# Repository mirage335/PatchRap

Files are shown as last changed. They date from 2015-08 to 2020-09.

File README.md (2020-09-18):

Copyright (C) 2015-2017 mirage335
See the end of the file for license conditions.
See license.txt for PatchRap license conditions.

'PatchPanel' initially designed for RepRap 3D printers to replace PCB terminal blocks with RJ45 jacks. Applicable to a wide variety of systems, including CNC machines, vehicles, factory automation, test equipment, and more.

Primary guidance for the standard should be taken from this README.

ANY CONFLICTING INFORMATION IN ANY OTHER DOCUMENTATION SHOULD BE DEFERRED TO THIS README UNLESS EXPLICITLY STATED OTHERWISE.

# Usage

GenericRap is the reference implementation, includes multiple connectors and headers to adapt RepRap motherboard terminals to internal step-down voltage converters, XT60 power connectors, shielded RJ45/8P8C connectors, and various peripherials (eg. steppers, limit switches, thermistors, hot-ends etc).

Breadboard friendly, the PCB layout includes appropriately spaced headers. In effect, a breadboard can be used as a backplane for power sharing and mechanical support, as well as to arrange even more wiring as needed.

Cat 6A S/FTP cabling recommended.

## Extract

Compacted design files are provided under '_out*' directories for inclusion into other projects. Please respect all relevant copyright licenses and distribute these files only with corresponding source (eg. the complete PatchRap repository).

To include these files in gEDA projects, a few routine modifications should be made.

Directory - create.

```
mkdir -p ./_out_PatchRap_symbols_reduced/footprints
```

File - project - must begin with...
```
elements-dir ./_out_PatchRap_symbols/footprints
elements-dir ./_out_PatchRap_breakouts/footprints

elements-dir ./_out_PatchRap_symbols_reduced/footprints
```

File - gafrc - must begin with...
```
(component-library "./_out_PatchRap_symbols")
(component-library "./_out_PatchRap_breakouts")
```

File - deleteme ...

```
echo '' > ./_out_PatchRap_symbols_reduced/footprints/deleteme
```

# Design
RJ45/8P8C connectors are among most convenient, cheapest connectors designed to provide high performance with commodity shielded twisted-pair cabling. High power transmission is documented, exceeding 2A/pin.

Besides 'patch panel' functions, surge suppressors and EMI filters are supported.

USA companies provide all parts in these schematics, excepting the RJ45 jacks and optional terminal blocks from TE Connectivity, a Swiss company.

Beware many RJ45 jacks are created from PCBs with thin traces unsuitable for high-current. Some RJ45 couplers may be more robust.

Pinouts are as follows, numbering by T568A standard.

## GenericIO	(Limit Switch, Depth Probe, Extruder, Stepper/Servo Driver, Servo Encoder, Radio)
	P3_W5 3 / 1/WG  - Vsys/Vcc
	P3_W6 3 \ 2/G   - pGND/sGnd
	P2_W4 2 - 3/WO  - Vext/Vmid/Avcc/SigAlt	(NC)								(LO)
	P1_W2 1 / 4/Bl  - Sig-/SigTx-		(sGND)				(Dir)		(I2C, UART)	
	P1_W1 1 \ 5/WBl - Sig+/SigTx+		(COM,ANA,Probe)			(Step)		(I2C, UART)	(IF)
	P2_W3 2 - 6/O   - sGND			(NO)
	P4_W7 4 / 7/WBr - PWMalternate/SigRx+	(Control, Servo, Heater)	(I2C,UART)			(RF)
	P4_W8 4 \ 8/Br  - PWMdirect/SigRx-	(Fan)				(I2C,UART)

## DigitalIO	(Display, SDCard, SPI)
	P3_W5 3 / 1/WG  - A0
	P3_W6 3 \ 2/G   - dRST
	P2_W4 2 - 3/WO  - Vext
	P1_W2 1 / 4/Bl  - MOSI			(I2C, UART)
	P1_W1 1 \ 5/WBl - MISO			(I2C, UART)
	P2_W3 2 - 6/O   - pGND
	P4_W7 4 / 7/WBr - SCK			(I2C, UART)
	P4_W8 4 \ 8/Br  - CS

## Steppers	(Stepper Motor)
	BEWARE! Comparison with LulzBot wiring suggests the third-party Fwd/Rev interconnection specification is inverted.
	Fwd/Rev is intended to be CW/CCW as seen from face of motor.
	P3_W5 3 / 1/WG  - Vsys
	P3_W6 3 \ 2/G   - pGND
	P2_W4 2 - 3/WO  - B+		Fwd(2A/Blue/Red)		Rev(1A/Green/Blue)
	P1_W2 1 / 4/Bl  - A+		Fwd(1A/Green/Blue)		Rev(2A/Blue/Red)
	P1_W1 1 \ 5/WBl - A-		Fwd(1B/Black/Yellow)		Rev(2B/Red/White)
	P2_W3 2 - 6/O   - B-		Fwd(2B/Red/White)		Rev(1B/Black/Yellow)
	P4_W7 4 / 7/WBr - B+		Fwd(2A/Blue/Red)*		Rev(1A/Green/Blue)*
	P4_W8 4 \ 8/Br  - B-		Fwd(2B/Red/White)*		Rev(1B/Black/Yellow)*

## LinearPSU (Lab Bench Power Supply)
	P3_W5 3 / 1/WG  - 5V
	P3_W6 3 \ 2/G   - Vee
	P2_W4 2 - 3/WO  - Vcc
	P1_W2 1 / 4/Bl  - GND
	P1_W1 1 \ 5/WBl - Vee
	P2_W3 2 - 6/O   - Vee
	P4_W7 4 / 7/WBr - 3.3V
	P4_W8 4 \ 8/Br  - Vee

See https://github.com/mirage335/LinearPSU/blob/master/Photo.jpg .

# Steper Motor Known Wiring Standards
All wiring assignments noted here must result in the same direction of rotation.

LulzBot Full Height and Half Height NEMA 17, SY42STH47-1504A
	Red/Blue is the color pair found most in common with other stepper motors.
	Assignment as to which pair is "A" or "B" is based on tracing back to the pin naming of the A4982 chip used by RAMBO Motherboard and Pololu stepper boards, and maintaining consistency with the Ap, Am, Bp, Bm naming used by 'cncio-sys.sch' for pin naming of the Pololu A498x stepper driver boards.
	P1_W1 1 \ 5/WBl - Red Motor	(A-)
	P1_W2 1 / 4/Bl  - Blue/White	(A+)
	P2_W4 2 - 3/WO  - Green		(B+)
	P2_W3 2 - 6/O   - Black		(B-)
	Tracing this mechanically to X-axis motion and typical Marlin firmware settings suggests this is in fact a 'Fwd' driving scheme, not 'Rev'.

OpenBuilds NEMA17
	Claimed SKU 623
	Claimed UPC 819368021264
	Undetermined wiring scheme.

# Ratings
Please beware the following ratings.
* Servo control through pin7 of "GenericIO" is intended for PWM servo position control, as opposed to rotary "Step/Dir" "Stepper/Servo Driver" control.
* Fan/Cooling through pin8 of "GenericIO" is intended for workpiece 'cooling'. A term used loosely in this context, implying any 
nonselective effector. Typically, thermoplastic filament deposition would control a fan blowing on the extruder nozzle, while Selective Laser Sintering, might control a defocused preheater.

* Vext is intended as logic power, and must never exceed 5.5V. Recommend 3.3V||5V depending on system needs.
* Vext may be used as a diode (eg. CDBU0530) OR-gated power bus if all connected devices can operate at 2.8V-5V.
* Vmid/Avcc are alternate uses for the Vext line, and may exceed 5.5V as appropriate.
* Vsys is intended for high-power delivery, and may be any voltage all attached devices are configured to tolerate. Recommend 12V||24V.
* Ground-referenced voltage (ie. wall current) is NOT guaranteed to remain isolated but nonetheless should only be considered for Vsys. Earth-ground and neutral may be bound to pGND/sGND.
* Maximum current into an RJ45 socket or breadboard is typically around 3A/pin. Consider using high-quality header/jumpers, and redundant pins, as appropriate.
* Voltage drops can be significant, especially across pGND/sGND. Take care to follow star-toplogy grounding to the greatest extent possible when accuracy counts.
* Rough changes to voltages can be made (eg. for fans) by high-power zener diodes (ie. 863-1N5919BG).
* Pins 7/8 of GenericIO may be repurposed for digital I2C/UART if needed, specifically for digital control of stepper driver.

# Safety
Use external balancer with LiPo batteries. Cheaply available from HobbyKing among other places.

Not Ethernet compatible, will destroy network hardware.

Do not unplug powered steppers.

Beware common grounding and other wiring issues.

ClassIV lasers are extraordinarily hazardous. Backscatter from the projected spot alone is sufficient to slice a retina. Avoid exposure, and wear eye protection.

Ground-referenced voltage (ie. wall current) applied to Vsys/Vee is NOT guaranteed to remain isolated from other circuits. Spark gap surge protectors specifically, among other faults, are expected to allow sustained connection of high-voltage ground-referenced current to all other circuits.

Testing all essential high current circuits to 30% above requirements is recommended. Such testing has not necessarily been performed. Any particular circuit may not have been designed to accommodate any significant current carrying capacity. Oil immersion may increase useful ampacity, though the risk of dissolution or fire must be considered carefully. Design goals are made on a best effort basis only, suggested but not guaranteed for further development, particularly for short narrow traces.
GenericRap and derivative PCBs - Typically 5A power. Between XT60 Connectors, 40A power.
Solderless Breadboard - Typically 3A per contact. Typically >6A total to gold, tin, lead or similarly plated square pin header 'power feeder' as used by GenericRap.
Wrapping Wire 30AWG "Kynar" Insulated - Typically 6A per wire.

Fire suppression or low flammability products may be mentioned for consideration of further development only. None are specifically recommended for any situation, none may have been tested in any relevant application, and no claim of effectiveness is made.

No claim of liability is made by anyone. Your accident is your accident. Use common sense, and follow all regulations. If you don't understand the safety features and limitations, don't use this circuitry or anything similar.

# FutureWork
* Battery charge control and overdischarge protection circuitry for regenerator.

# Reference
https://www.inventables.com/technologies/stepper-motor-nema-17
http://www.rcgroups.com/forums/showthread.php?t=2387201
https://en.wikipedia.org/wiki/Parallel_ATA

http://electronut.in/attiny10-hello/

http://www.hobbyking.com/hobbyking/store/__26136__Turnigy_DLUX_LIPO_Battery_Cell_Display_and_Balancer_2S_6S_.html

https://www.youtube.com/watch?v=EnanV3dLPJ0

http://reprap.org/wiki/Duet

https://miscsolutions.wordpress.com/paneldue/
http://blog.think3dprint3d.com/2015/04/duex4-v02a-minor-updates.html
http://blog.think3dprint3d.com/2015/02/reprapfirmware-config-files.html

http://blog.think3dprint3d.com/

http://www.linengineering.com/resources/wiring_connections.aspx

https://www.quintolubric.com/wp-content/uploads/articles_2018/IP_MPT_Int_04_2017_S56_59_reprint.pdf
https://youtu.be/bEtlikCMRWM?t=164

https://smile.amazon.com/dp/B008HQ6XNC/?coliid=I3TVNJLXY6X9TV&colid=3OTBRPJLKJWP5&psc=1&ref_=lv_ov_lig_dp_it

https://www.htgsupply.com/products/the-watch-dog-automatic-fire-extinguisher-12-kg/

https://www.youtube.com/watch?v=il9bNWn66BY
https://duet3d.dozuki.com/Wiki/Choosing_a_Z_probe
https://www.youtube.com/watch?v=rIb4wtEoE2w
https://hackaday.com/2019/09/01/force-sensitive-resistor-takes-the-pain-out-of-bed-leveling/
https://reprap.org/wiki/Z_probe
https://reprap.org/wiki/Underbed_Piezo-electric_sensors

https://www.youtube.com/watch?v=Bq2AcUwrd5Q
https://www.youtube.com/watch?v=VwdnGbI5ls8

https://www.instructables.com/id/Make-a-water-block-out-of-a-heatsink-for-less-than/

https://www.linengineering.com/resources/wiring-diagrams
https://cdn11.bigcommerce.com/s-itwgldve/product_images/uploaded_images/imgpsh-fullsize-4-22403.1539714162.jpg
http://download.lulzbot.com/AO-100/hardware/electronics/spec_sheets/SY42STH47-1504A_stepperMotors.pdf

https://download.lulzbot.com/TAZ/6.02/production_parts/electronics/RAMBo/docs/RAMBo-1.1b-user-manual.pdf

https://ohai.lulzbot.com/project/taz6-rambo-13l-14-upgrade/
https://ohai.lulzbot.com/media/uploads/PinoutTAZ6_fixed.jpg.600x0_q85_fIgdq3t.jpg
https://cdn.shopify.com/s/files/1/1223/5992/products/Rambo14a_1024x1024_aa89364b-1778-44dc-817f-51a350a93580_1024x1024.jpg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

https://hackaday.com/2019/09/10/diy-watertight-junction-box-for-serious-outdoor-sealing/

# Copyright
This file is part of PatchRap.

PatchRap is free software: you can redistribute it and/or modify
it under the terms of the GNU General Public License as published by
the Free Software Foundation, either version 3 of the License, or
(at your option) any later version.

PatchRap is distributed in the hope that it will be useful,
but WITHOUT ANY WARRANTY; without even the implied warranty of
MERCHANTABILITY or FITNESS FOR A PARTICULAR PURPOSE.  See the
GNU General Public License for more details.

You should have received a copy of the GNU General Public License
along with PatchRap.  If not, see <http://www.gnu.org/licenses/>.

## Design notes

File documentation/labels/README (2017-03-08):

_ColorCode_
Label background color codes identify subordinate standards followed, as well risk of equipment damage upon improper connection, in order. End-user functionality should be kept to BLUE, BLACK, WHITE, or lower risk networks.

YELLOW (ffff00) - RESERVED

MAGENTA (ff00ff) - High-voltage high-current may be applied to any pin. Stepper motor, linear PSU.

PURPLE (8000ff) - RESERVED

ORANGE (ff8000) - GenericIO Compliant. High-voltage/current peripherial. Hot-end.

GREEN (00ff00) - GenericIO Compliant. Peripherial. Limit switch, thermistor.

TEAL (00ffff) - RESERVED

BLUE (0000ff) - GenericIO Compliant. Digital logic or high-reliability network. All power <5V. All signals <3.3V. Fuse, resistor, diode, transformer, and transient-voltage suppression may be in place.

BLACK (000000) - DigitalIO Compliant. All pins strictly limited to <3.3V. End-user digital peripherial. Graphical display.
WHITE (ffffff) - GenericIO Compliant. All pins strictly limited to <3.3V. End-user analog peripherial. Thermistor.

_Checkboxes_
Whitespace is provided as a multi-use checkbox, or other arbitrary label. Reading from left-to-right, a vertical line "|" should only be the last symbol if cable connections at both ends were most recently known to be valid.

Mark "|" when connection is validated by continutiy test. Mark "-" or "." or "x" when either end of the cable is not certainly attached to correct device type.

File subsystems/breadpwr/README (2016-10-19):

Breadboards typically have 0.1" spacing, leading to a 1.7in distance between inner power rails, as reflected in silkscreen lines. Measured breadboards have shown a -0.050in (-50mil) delta from this, as reflected in the actual PCB layout spacing with a 25mil delta.

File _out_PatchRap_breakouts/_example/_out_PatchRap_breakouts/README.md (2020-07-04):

Component schematic symbols and footprints intended to simplify electrical connections between standard cables, inexpensive quick-change connectors, and tools.

Beware these files are intended to rapidly create specialized adapters (ie. breakouts) ONLY.

Such simplified adapters may have several potentially dangerous limitations.

* Proper labeling with universally unique indicators as to known compatible equipment is *strongly* encouraged.
* Justification of necessity to be documented or linked as feasible with relevant design files is *strongly* encouraged.
* May be dangerously incompatible with any equipment not specifically designed for.
* May not be standards compliant.

* Binding tabs for zip tie, foil, and plastic sheets, at each RJ45 jack, for shielding, are *strongly* encouraged.

# Connectors

RJ45 - Typically 5A/contact (without powered dis/connects).
XT60 - Typically 60A/contact .
Solderless Breadboard - Typically <3A/contact .

Mezzanine 60pin 0.3A/contact

IDC (12pin) - Offset Pins/Vias typically 3A/contact (completely untested) .

Mounting hole forced ring of contacts - 1mm balls typically 3A/contact (completely untested) .

Screw Terminals - 490-TB001-500-09BE (9-position, 5mm pitch) or similar with wire space behind clamp mechanism. Beware these may not be able to establish or maintain adequate mechanical or electrical contact.

Barrier Terminal Blocks - 38700-6109 (9-position, 8.26mm pitch) or similar.

Multi-Dimensioned Wiring Solder Points - insulated portions of wires must be woven through as many plated vias as possible. Additionally, zip ties with spacing beads (possibly a standard 3D printed part) may be needed to ensure strain relief for potentially fragile solder joints.
0.50mm (26AWG 0.4049mm, 30AWG 0.2546mm)
0.75mm (22AWG 0.6438mm)
1.25mm
2.00mm

Breakaway Lines - Using only single layers or well separated traces across a marked line on a PCB may allow the PCB to be cut or broken at that point and subsequently reconnected by any board-to-board connection mechanism.

# Rejected

Card edge connectors, when compact (ie. M.2), typically do not offer substantial improvements (ie. 0.5A/contact) over Mezzanine connectors.

Rivets typically may not adequately accommodate spacing for additional Mezzanine connectors, and may be labor intensive to install.

Wire wrap may requrire pin headers which are too expensive in some situations.

Wiring pen (solderable enamel wire) may be too labor intensive in some situations.

Standard processor sockets (eg. LGA2011) may have a high upfront cost, and possible long-term availability issues. Multiple mezzanine connectors per PCB may offer comparable performance (even if practical limits exceed 1kA/2000pins). However, these sockets have not been ruled out for all applications, particularly extremely high-current high-voltage switching modules requiring transistor cascodes, multiple isolated inputs, and watercooling.

Solder bridges from one PCB to the next have in some situations proven labor intensive and fragile, sometimes requiring a stereomicroscope to perform efficiently.

Friction contact between exposed PCB traces may be unreliable due to PCB manufacturing thickness variations or insufficient elasticity.

# Safety

Use external balancer with LiPo batteries. Cheaply available from HobbyKing among other places.

Not Ethernet compatible, will destroy network hardware.

Do not unplug powered steppers.

Beware common grounding and other wiring issues.

ClassIV lasers are extraordinarily hazardous. Backscatter from the projected spot alone is sufficient to slice a retina. Avoid exposure, and wear eye protection.

Ground-referenced voltage (ie. wall current) applied to Vsys/Vee is NOT guaranteed to remain isolated from other circuits. Spark gap surge protectors specifically, among other faults, are expected to allow sustained connection of high-voltage ground-referenced current to all other circuits.

Testing all essential high current circuits to 30% above requirements is recommended. Such testing has not necessarily been performed. Any particular circuit may not have been designed to accommodate any significant current carrying capacity. Oil immersion may increase useful ampacity, though the risk of dissolution or fire must be considered carefully. Design goals are made on a best effort basis only, suggested but not guaranteed for further development, particularly for short narrow traces.
GenericRap and derivative PCBs - Typically 5A power. Between XT60 Connectors, 40A power.
Solderless Breadboard - Typically 3A per contact. Typically >6A total to gold, tin, lead or similarly plated square pin header 'power feeder' as used by GenericRap.
Wrapping Wire 30AWG "Kynar" Insulated - Typically 6A per wire.

Fire suppression or low flammability products may be mentioned for consideration of further development only. None are specifically recommended for any situation, none may have been tested in any relevant application, and no claim of effectiveness is made.

No claim of liability is made by anyone. Your accident is your accident. Use common sense, and follow all regulations. If you don't understand the safety features and limitations, don't use this circuitry or anything similar.

SAFETY DOCUMENTATION HERE TO BE AN EXACT COPY OF SAFETY DOCUMENTATION PROVIDED AS 'README' FOR "PatchRap" .

# Copyright

Please see 'license_PatchRapBreakouts_symbol_and_footprint_files.txt' . To the extent feasible, efforts have been made to ensure all source code is available, and all copyright license terms are fully respected. Some named files under this directory were obtained from gedasymbols.org under a 'GPL license'. All files under this directory in the absence of any license explicitly stated in the named license file or any prior license are intended to be public domain.

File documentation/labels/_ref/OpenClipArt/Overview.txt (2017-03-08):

_Reference_
https://openclipart.org/image/800px/svg_to_png/92233/warning-02.png&disposition=attachment
https://openclipart.org/image/300px/svg_to_png/77083/1280913718.png&disposition=attachment
https://openclipart.org/image/300px/svg_to_png/212874/RootTerminal.png&disposition=attachment
https://openclipart.org/image/300px/svg_to_png/190966/earthquake.png&disposition=attachment

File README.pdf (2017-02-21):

3 / 1 - Vsys/Vcc
3 \ 2 - pGND/sGnd
2 - 3 - Vext/Vmid/Avcc/SigAlt | (NC) | | (LO)
1 / 4 - Sig-/SigTx- | (sGND) | (Dir) | (I2C, UART)
1 \ 5 - Sig+/SigTx+ | (COM,ANA,Probe) | (Step) | (I2C, UART) (IF)
2 - 6 - sGND | (NO)
4 / 7 - PWMalternate/SigRx+ | (Control, Servo, Heater) | (I2C,UART) (RF)
4 \ 8 - PWMdirect/SigRx- | (Fan) | | (I2C,UART)

3 / 1 - A0
3 \ 2 - dRST
2 - 3 - Vext
1 / 4 - MOSI | (I2C, UART)
1 \ 5 - MISO | (I2C, UART)
2 - 6 - pGND
4 / 7 - SCK | (I2C, UART)
4 \ 8 - CS

3 / 1 - Vsys
3 \ 2 - pGND

GenericIO (Limit Switch, Depth Probe, Extruder,

## Stepper Driver, Radio)

## DigitalIO (Display, SDCard, SPI)

## Steppers (Stepper Motor)

2 - 3 - B+ | Fwd(2A/Blue/Red) | Rev(1A/Green/Blue)
1 / 4 - A+ | Fwd(1A/Green/Blue) | Rev(2A/Blue/Red)
1 \ 5 - A- | Fwd(1B/Black/Yellow) | Rev(2B/Red/White)
2 - 6 - B- | Fwd(2B/Red/White) | Rev(1B/Black/Yellow)
4 / 7 - B+ | Fwd(2A/Blue/Red)* | Rev(1A/Green/Blue)*
4 \ 8 - B- | Fwd(2B/Red/White)* | Rev(1B/Black/Yellow)*

3 / 1 - 5V
3 \ 2 - Vee
2 - 3 - Vcc
1 / 4 - GND
1 \ 5 - Vee
2 - 6 - Vee
4 / 7 - 3.3V
4 \ 8 - Vee
See https://github.com/mirage335/LinearPSU/blob/master/Photo.jpg .

Please beware the following ratings.

Vext is intended as logic power, and must never exceed 5.5V. Recommend 3.3V||5V depending on system needs.
Vext may be used as a diode (eg. CDBU0530) OR-gated power bus if all connected devices can operate at 2.8V-5V.
Vmid/Avcc are alternate uses for the Vext line, and may exceed 5.5V as appropriate.
Vsys is intended for high-power delivery, and may be any voltage all attached devices are configured to tolerate. Recommend 12V||24V.
Ground-referenced voltage (ie. wall current) should only be considered for Vsys. Earth-ground and neutral may be bound to pGND/sGND.
Maximum current into an RJ45 socket or breadboard is typically around 3A/pin. Consider using high-quality header/jumpers, and redundant pins, as appropriate. Voltage drops can be significant, especially across pGND/sGND. Take care to follow star-toplogy grounding to the greatest extent possible when accuracy counts.
Rough changes to voltages can be made (eg. for fans) by high-power zener diodes (ie. 863-1N5919BG).
Pins 7/8 of GenericIO may be repurposed for digital I2C/UART if needed, specifically for digital control of stepper driver.

## LinearPSU

# Ratings

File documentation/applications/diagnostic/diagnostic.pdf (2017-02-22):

# Soaring Industries

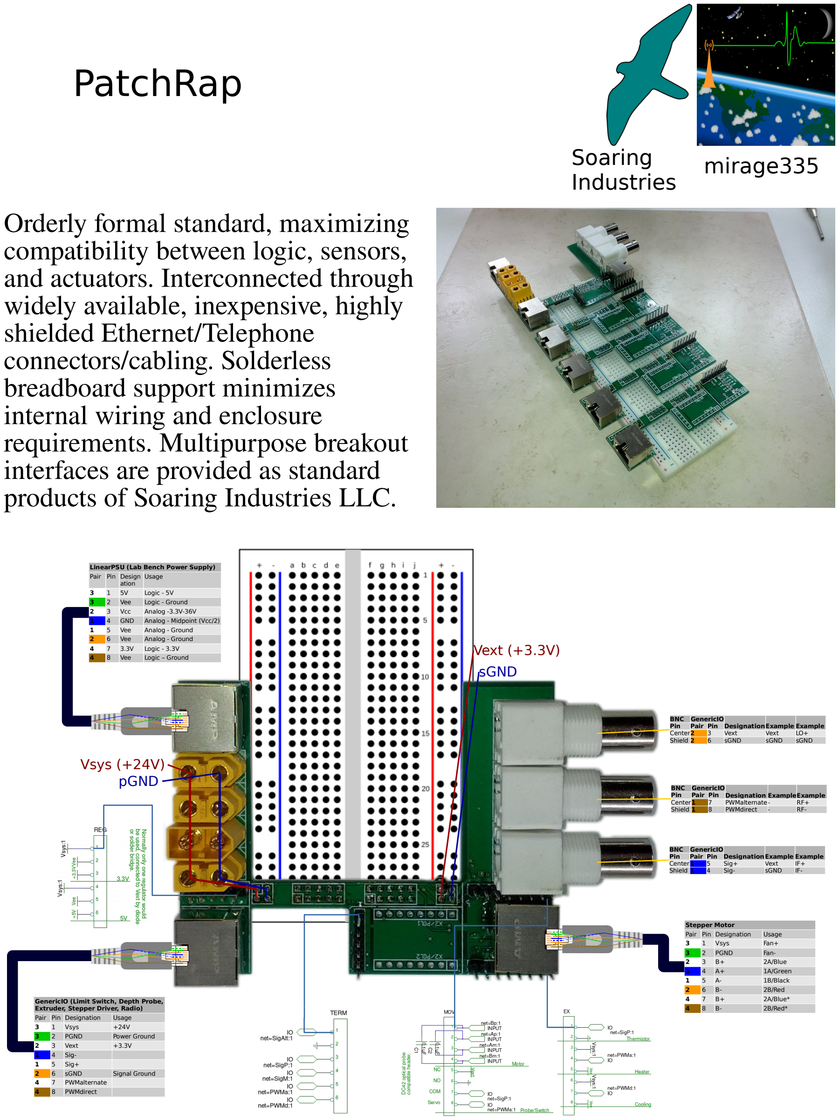
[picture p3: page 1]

# PatchRap

# Orderly formal standard, maximizing

compatibility between logic, sensors,

# and actuators. Interconnected through widely available, inexpensive, highly shielded Ethernet/Telephone connectors/cabling. Solderless breadboard support minimizes internal wiring and enclosure requirements. Multipurpose breakout interfaces are provided as standard

products of Soaring Industries LLC.

# mirage335

GenericIO (Limit Switch, Depth Probe, Extruder, Stepper Driver, Radio)
Pair | Pin | Designation | Usage
3 | 1 | Vsys | +24V
3 | 2 | PGND | Power Ground
2 | 3 | Vext | +3.3V
1 | 4 | Sig-
1 | 5 | Sig+
2 | 6 | sGND | Signal Ground
4 | 7 | PWMalternate
4 | 8 | PWMdirect

# Vsys (+24V)

LinearPSU (Lab Bench Power Supply)
Pair | Pin | Design ation | Usage
3 | 1 | 5V | Logic - 5V
3 | 2 | Vee | Logic - Ground
2 | 3 | Vcc | Analog -3.3V-36V
1 | 4 | GND | Analog - Midpoint (Vcc/2)
1 | 5 | Vee | Analog - Ground
2 | 6 | Vee | Analog - Ground
4 | 7 | 3.3V | Logic - 3.3V
4 | 8 | Vee | Logic – Ground

Stepper Motor
Pair | Pin | Designation | Usage
3 | 1 | Vsys | Fan+
3 | 2 | PGND | Fan-
2 | 3 | B+ | 2A/Blue
1 | 4 | A+ | 1A/Green
1 | 5 | A- | 1B/Black
2 | 6 | B- | 2B/Red
4 | 7 | B+ | 2A/Blue*
4 | 8 | B- | 2B/Red*

# pGND

# Vext (+3.3V) sGND

BNC | GenericIO | DesignationExample Example
Pin | Pair | Pin
Center1 | | 5 | Sig+ | Vext | IF+
Shield 1 | | 4 | Sig- | sGND | IF-
BNC | GenericIO | Designation ExampleExample PWMalternate- | | RF+
Pin Center1 | Pair | Pin 7
Shield 1 | | 8 | PWMdirect | - | RF-
BNC | GenericIO | DesignationExample Example
Pin | Pair | Pin
Center2 | | 3 | Vext | Vext | LO+
Shield 2 | | 6 | sGND | sGND | sGND

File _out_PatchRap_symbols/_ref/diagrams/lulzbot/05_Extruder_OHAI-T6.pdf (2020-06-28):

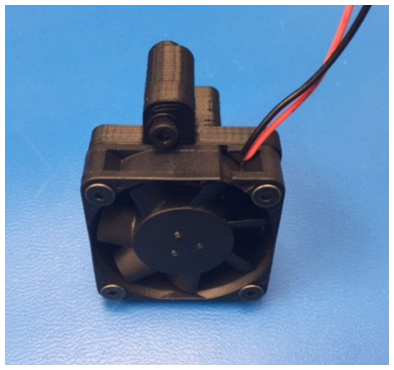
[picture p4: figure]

### Taz 6- Nutmeg Generation Extruder Assembly

10) Prep sub-assemlies

Utiltize OHAI for Hexagon Hot End to build a .5mm Hot End Assembly

Utilize OHAI for Extruder Body sub-assembly to build a Extruder Body assembly (Herringbone gears will be Green).

20) Attach X end stop switch to the Fan Duct, RIGHT (PP-GP0212). Note the Orientation of the switch, this is critical. Tighten screws to 3 in-lbs (~.35N-m) Use:
2x- M2 x 6 SHCS
2x- M2 SS washer
30) Prepare the Hexagon heat sink fan and attach to the Hexagon Hot End Heat Sink fan duct (PP-GP0232 ) with inserts already installed. Note orientation of fan. Use: 4x- M3x 12 SHCS tighten to 8 in-lbs (~.9N-m)

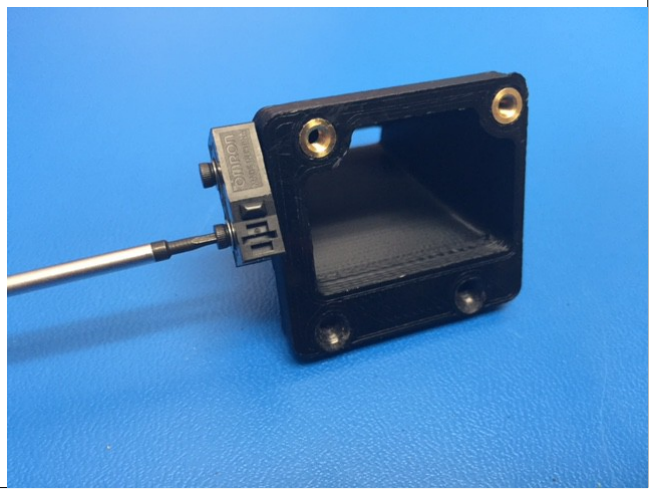
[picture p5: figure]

40) Plugging Order for the devices to be connected to a 16 pin Molex connector

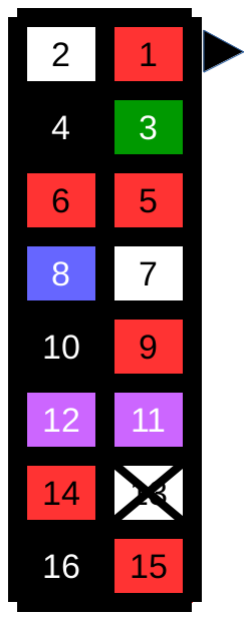
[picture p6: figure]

1- Red- Motor
2- White- Motor
3- Green- Motor
4- Black- Motor
5- Red- Heater Cartridge
6- Red- Heater Cartridge
7- White- Dual fan
8- Blue- Dual Fan
9- Red- Heat Sink Fan
10- Black- Heat Sink Fan
11- Purple- Switch
12- Purple- Switch
13- Empty
14- Red- Ground Wire
15- Red- Thermistor
16- Black- Thermistor

50) Attach the Hot End Assembly to the Dual fan extruder mount v0.5

Utilize OHAI for Hexagon Hot End .5mm assembly
Use:
1x- Extruder Mount TAZ6 (PP-GP0208)
1x- .5mm Hexagon Hot End assembly
1x- Extruder body assembly (PP-GP0186) 1x- Hot End adapter plate
2x- M3x 12 SHCS
2x- M3 nut SS

Connect the Heater Cartridge and Thermistor to the 16 pin connector attached to the motor

60) Connect the Hexagon Hot End ground wire (220mm long) to the hot end. Route the ground wire behind the hot end, Plug ground wire into the 16pin connector that is attached to the motor.

Use:
1x- 4-40 BHCS SS
1x- 4-40 star washer
70) Attach the Left (PP-GP0211) and Right (PP-GP0212) fan ducts to the Extruder Mount TAZ6

Use:
2x- M3 x 12 FHS (for each duct), tighten to 8 in-lbs (~.9 N-m)

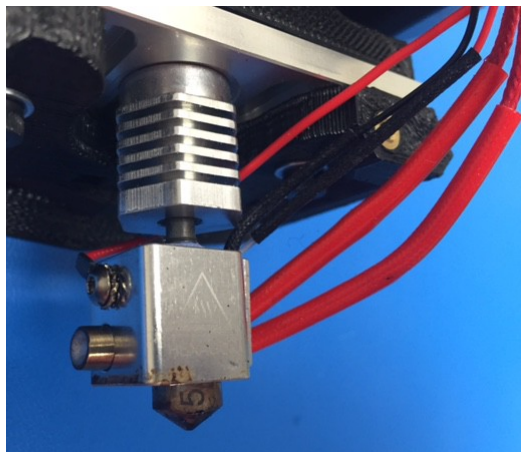
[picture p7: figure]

80) Prepare the Hexagon hot end dual fan sub-assembly

Layout the assembly in front of the Extruder with the fan that has the longest wire cut length to the left of the extruder and the shortest to the right side of the extruder.

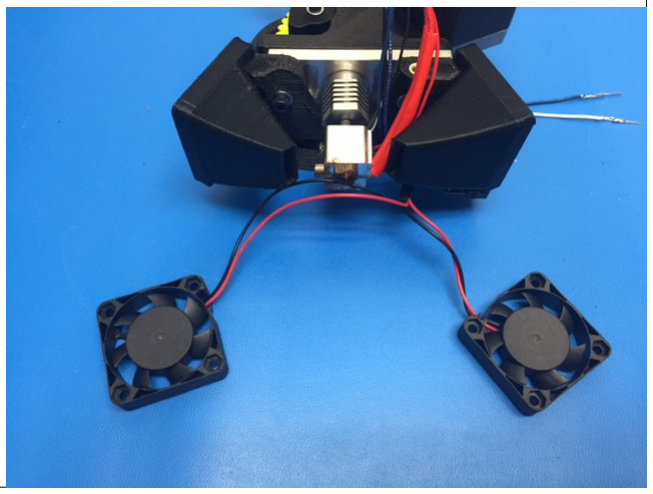
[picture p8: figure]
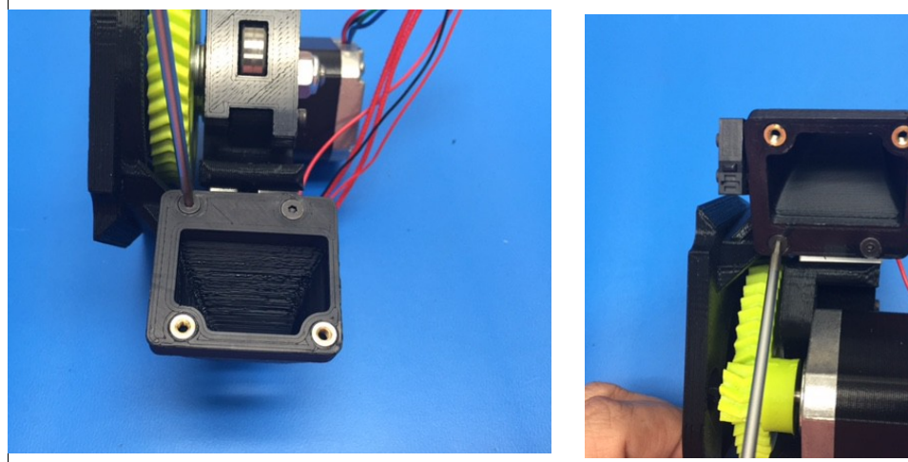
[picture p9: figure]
Left; Right
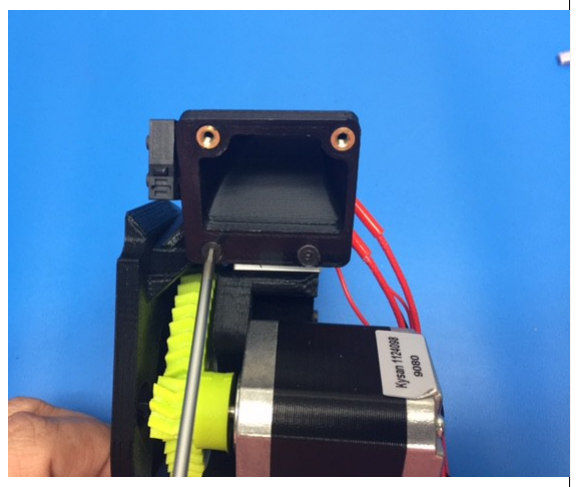
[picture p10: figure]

100) Attach the short fan to the Duct, Right. Note Orientation of the wires exiting the fan.
Use: 2x- M3x 12 SHCS; tighten to 8 in-lbs (~.9 N-m)
90) Attach the long fan to the Duct, Left. Note Orientation of the wires exiting the fan.
Use: 2x- M3x 12 SHCS; tighten to 8 in-lbs (~.9 N-m)

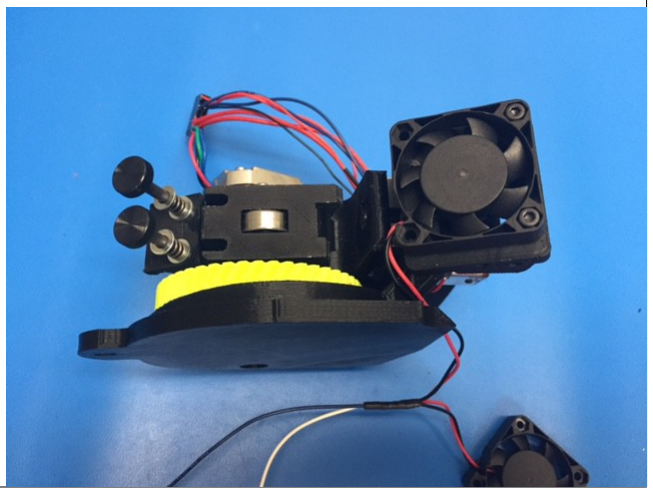
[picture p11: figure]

110) Route the long fan wire along the back of the mount, secure in place with a Ty wrap as shown, proper routing is critical

Connect the Heater Cartridge and Thermistor to the 16 pin connector attached to the motor

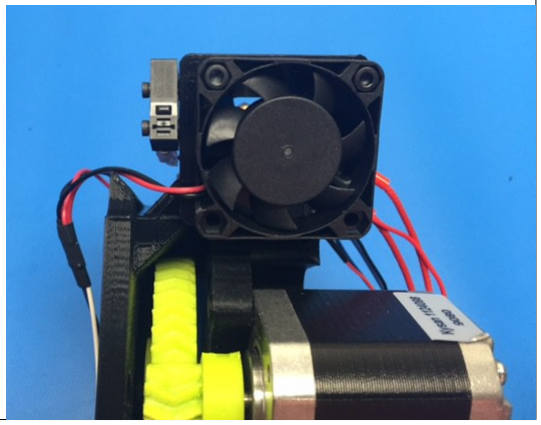
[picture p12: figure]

120) Connect Switch to the 16 pin connector, connect to the switch terminals shown; route wires as shown
Use:
2x- 190mm Blue wire with terminals and Faston PIDGN connector

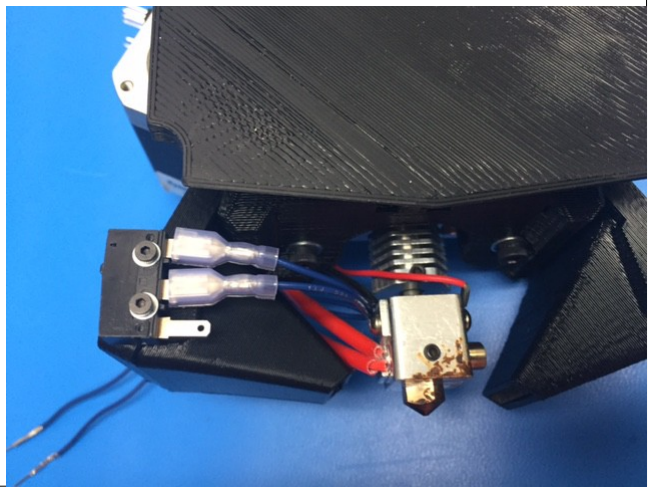
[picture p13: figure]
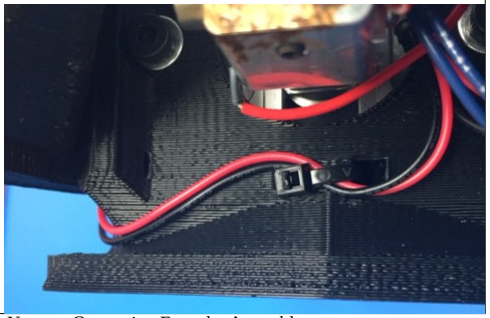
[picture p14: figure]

130) Attach Heat Sink Fan Duct to assembly
Route wires into the duct channel as shown, secure duct to assembly Use:
1x- M3x 25 SHCS; 1x- M3 washer; ; tighten to 8 in-lbs (~.9 N-m)
140) Attach Heat Sink fan to 16 position connector
Wrap 3/4” panduit (110mm length) around wires starting at the bottom of the connector and completing as far down the wire bundle as possible
Secure the panduit to the wire bundle with one Ty Wrap; Position the Ty Wrap approximately where shown

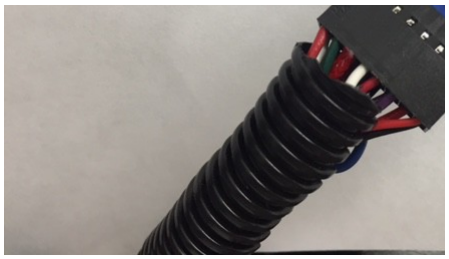
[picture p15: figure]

### 150) Apply the Connect Up label onto the Pin 1 side of the connector nearest the pins extending from the connector

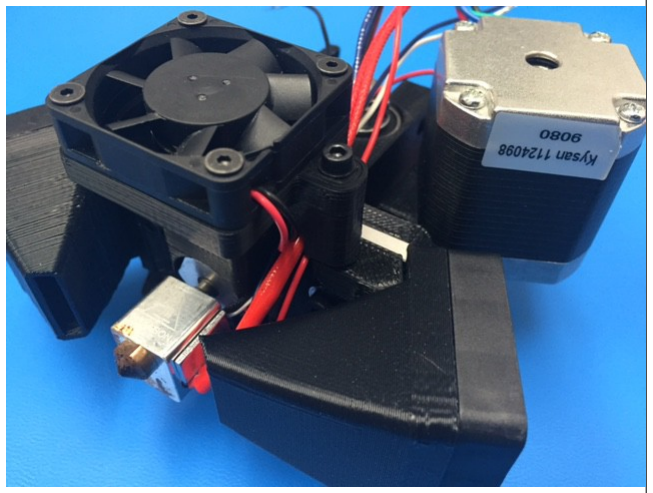
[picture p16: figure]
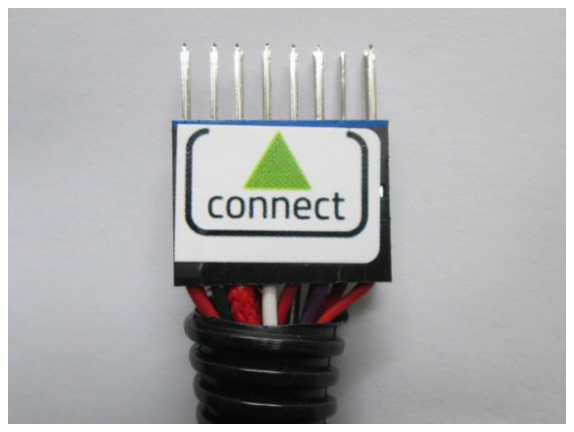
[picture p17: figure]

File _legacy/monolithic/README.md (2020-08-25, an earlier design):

Obsolete PatchRap PCB used only for TazMega. Not recommended for new designs.

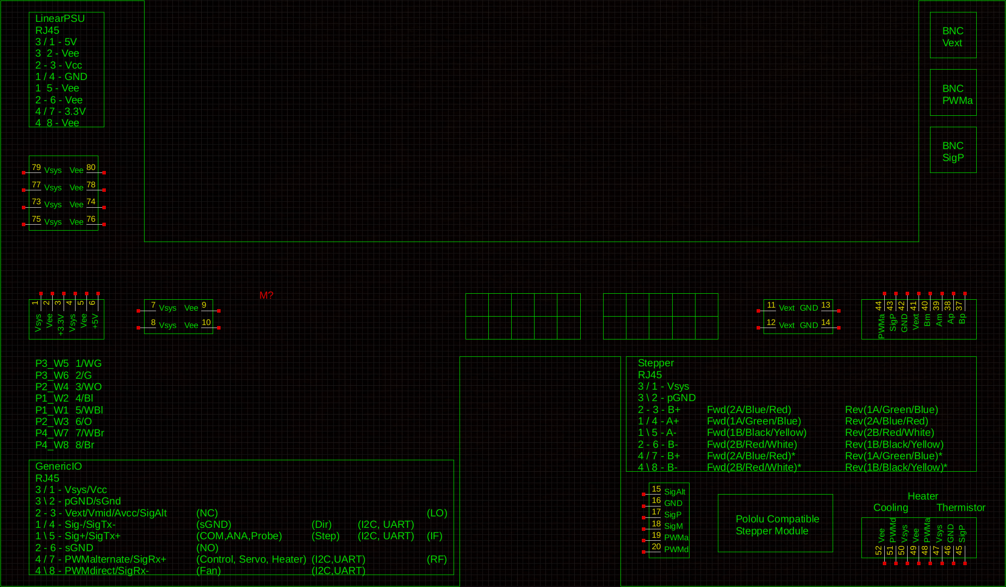
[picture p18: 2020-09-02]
GenericRap_Pinout.png

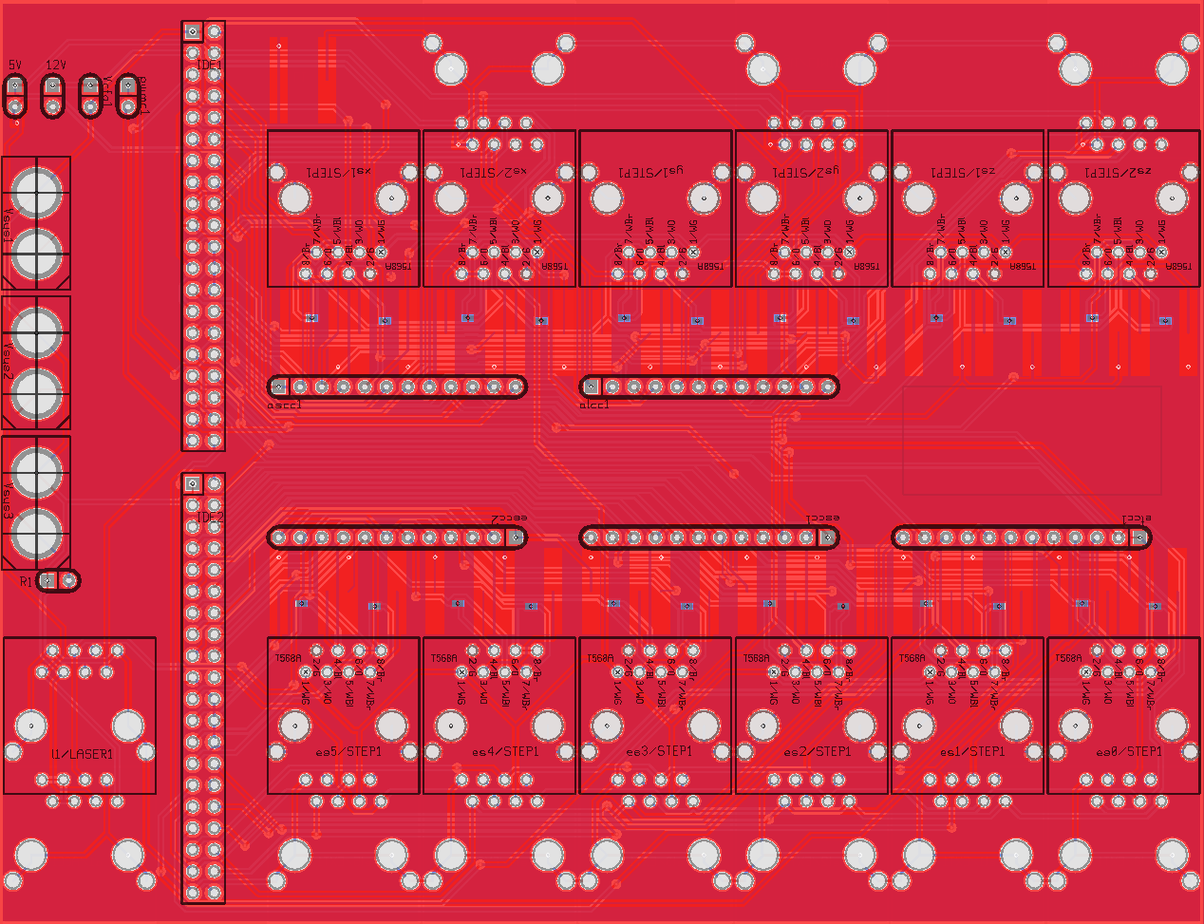
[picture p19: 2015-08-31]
PatchRap.pcb.png

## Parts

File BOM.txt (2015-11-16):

1 * S/FTP Cat6A Cable - http://www.amazon.com/dp/B004NPL4YE/?tag=hacdc-20

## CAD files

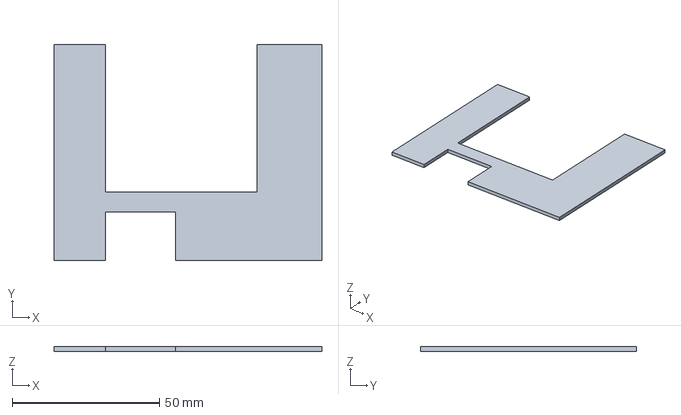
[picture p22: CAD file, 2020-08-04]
_out/_dev/PatchRap_FreeCAD/GenericRap/GenericRap.FCStd
90.9 x 73.4 x 1.59 mm

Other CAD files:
_out/_dev/PatchRap_FreeCAD/GenericRap/GenericRap.obj

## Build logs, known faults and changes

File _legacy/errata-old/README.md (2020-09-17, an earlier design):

Documents a missing trace from an older, but otherwise electrically compatible, version of the PatchRap GenericRap PCB.

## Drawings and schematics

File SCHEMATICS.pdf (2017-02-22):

## 1 Vsys 2 pGND

## 3 Vext 4 sGND

## 5 SigP 6 SigM

## 8 PWMd

## 7 PWMa

10 Ap

9 Bp

11 Am
12 Bm

## cncio

Vsys:1 | X2
Vee

Vext

## net=SigP:1

IO

## net=SigM:1

IO

## net=PWMa:1

IO

## net=PWMd:1

IO

1 | SigAlt−Vext
2 | SigP
5 | PWMa
6 | PWMd
3 | SigM
4 | sGND

## ANALOG

X3

## net=SigM:1

## IO net=SigP:1

IO

## net=SigAlt:1

IO

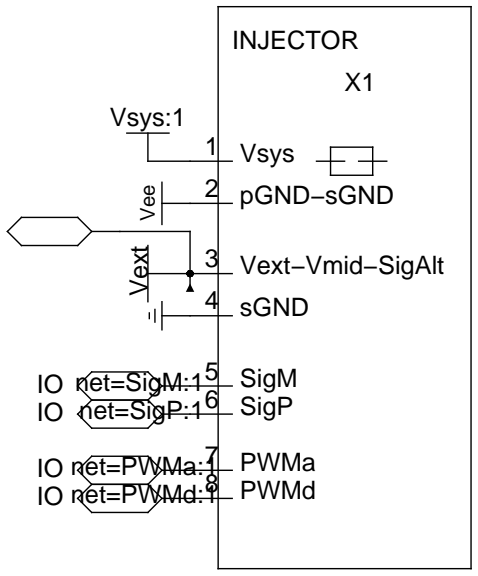
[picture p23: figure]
Vsys; pGND−sGND; Vext−Vmid−SigAlt; sGND; SigM 6; SigP; PWMd; PWMa; INJECTOR X1; Vee; Vsys:1; IO net=SigP:1; IO net=SigM:1; IO net=PWMa:1 IO net=PWMd:1

## Vext net=SigAlt:1

IO

## net=PWMa:1

IO

## net=PWMd:1

IO

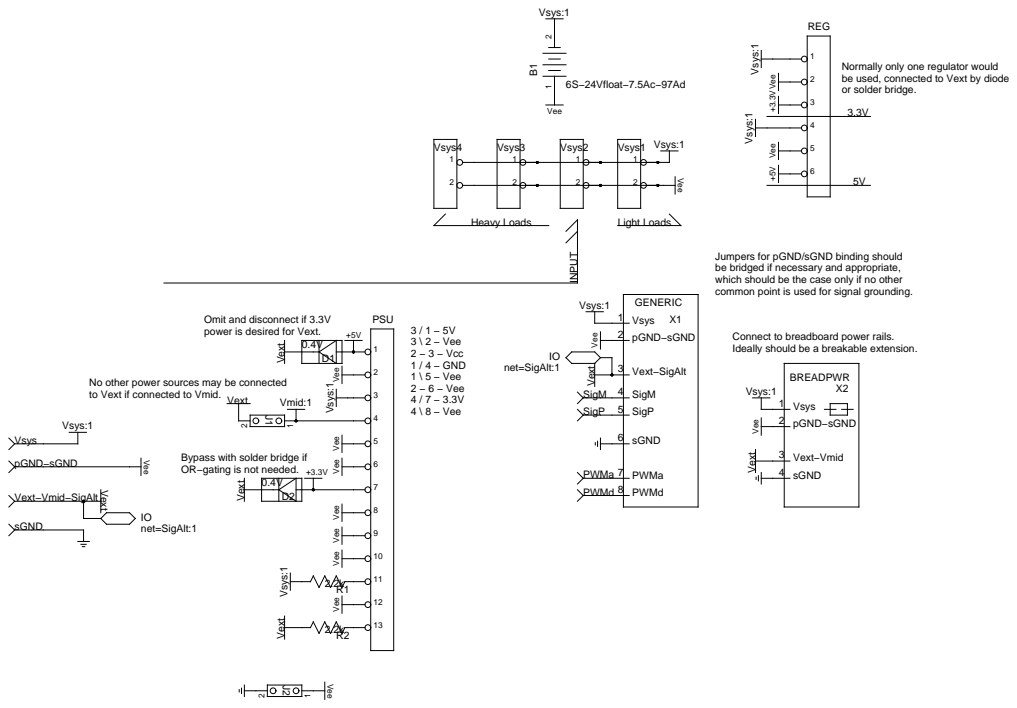
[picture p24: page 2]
Vsys; pGND−sGND; sGND; Vee; Vext; Vsys:1; Vext D2 0.4V; 3 / 1 − 5V 3 \ 2 − Vee 2 − 3 − Vcc 1 / 4 − GND 1 \ 5 − Vee 2 − 6 − Vee 4 / 7 − 3.3V 4 \ 8 − Vee; Vext−SigAlt; SigM; SigP; PWMa; PWMd; GENERIC X1; Vext−Vmid; BREADPWR X2; Vmid:1; Vsys4; INPUT; Heavy Loads; Light Loads; net=SigAlt:1; Vsys3; Vsys2; Vsys1; 6S−24Vfloat−7.5Ac−97Ad; Vee +5V; REG; PSU; Vext R2; Vee Vee

Normally only one regulator would
be used, connected to Vext by diode
or solder bridge.

Jumpers for pGND/sGND binding should
be bridged if necessary and appropriate,
which should be the case only if no other
common point is used for signal grounding.

Omit and disconnect if 3.3V
power is desired for Vext.

Connect to breadboard power rails.
Ideally should be a breakable extension.

Vee Vee Vee Vee No other power sources may be connected to Vext if connected to Vmid. SigM SigP PWMa PWMd

Bypass with solder bridge if
OR−gating is not needed.

Vext−Vmid−SigAlt

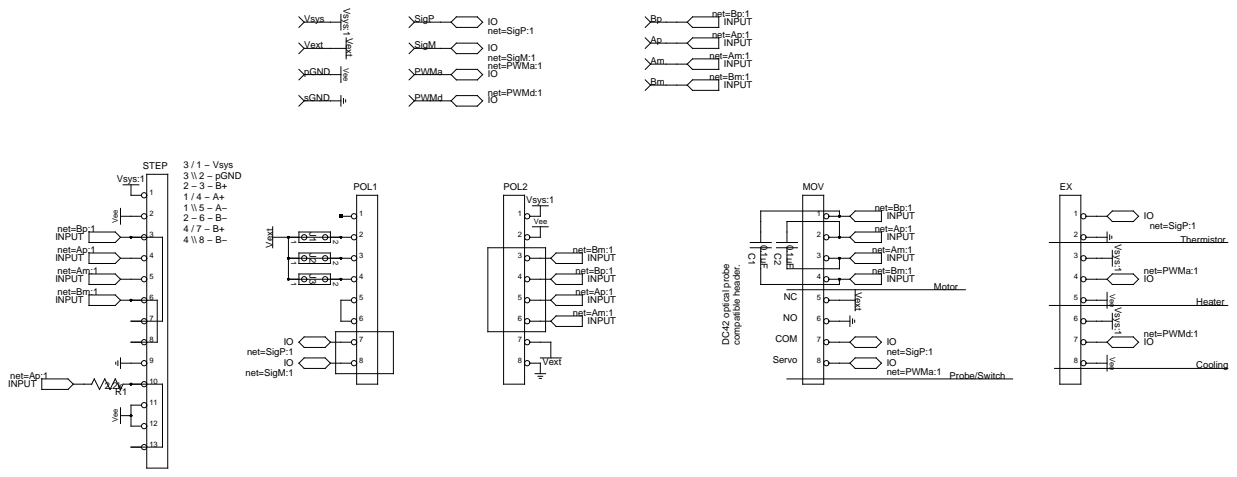
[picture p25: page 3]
net=Bm:1 INPUT; net=Am:1 INPUT; Vee; 3 / 1 − Vsys 3 \\ 2 − pGND 2 − 3 − B+ 1 / 4 − A+ 1 \\ 5 − A− 2 − 6 − B− 4 / 7 − B+ 4 \\ 8 − B−; Vsys:1; Vext; POL1; POL2; net=SigP:1; net=SigM:1; net=Am:1 INPUT net=Bm:1 INPUT; net=PWMa:1; MOV; DC42 optical probe; Servo; Motor; Probe/Switch; Vee Vee; Thermistor; Heater; Cooling; pGND; Vsys; sGND; Vext Vext; net=PWMa:1 IO; net=PWMd:1 PWMd; PWMa; STEP

Vsys:1 Vee SigP SigM net=SigP:1 IOnet=SigM:1 IO

net=Bp:1 INPUT

net=Ap:1 INPUT

net=Bm:1
INPUT

Vsys:1 net=PWMa:1

compatible header. COM

Vsys:1 net=PWMd:1

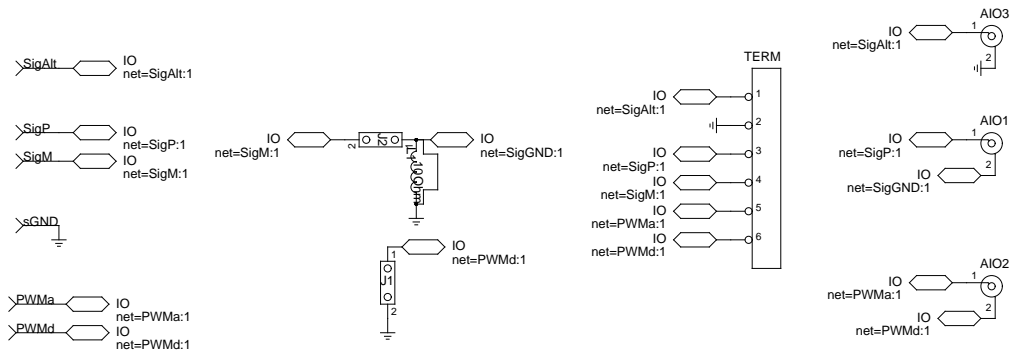
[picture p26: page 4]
net=SigP:1; net=SigAlt:1; net=PWMa:1; L1 10Ohm; net=SigM:1; net=SigGND:1; sGND; SigM; SigP; SigAlt; net=SigAlt:1 IO; net=PWMd:1; PWMd; PWMa; TERM; AIO3; AIO1; AIO2

## Vext capacitor should be omitted if

## GEN

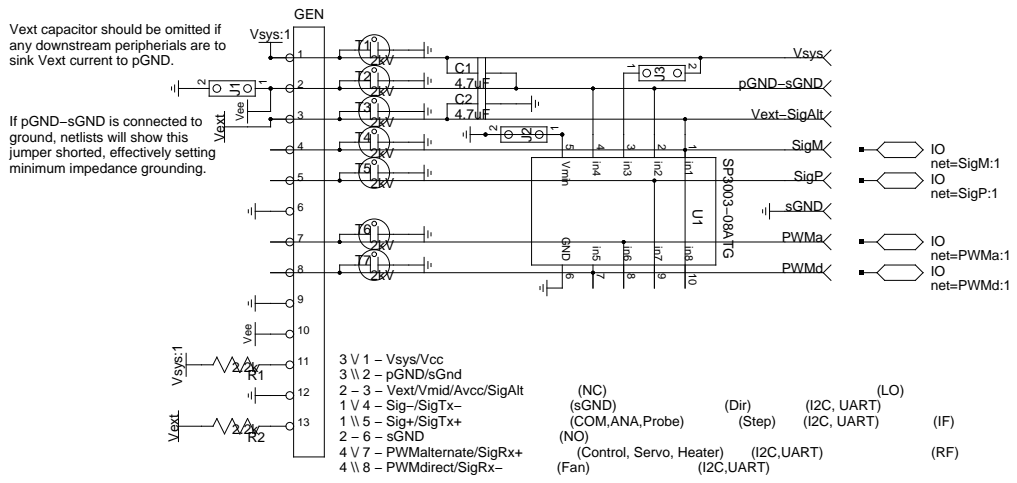
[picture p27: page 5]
3 \/ 1 − Vsys/Vcc 3 \\ 2 − pGND/sGnd; 2 − 3 − Vext/Vmid/Avcc/SigAlt; 1 \/ 4 − Sig−/SigTx−; (sGND); (Dir); (I2C, UART); 1 \\ 5 − Sig+/SigTx+; (COM,ANA,Probe); (Step); 2 − 6 − sGND; 4 \/ 7 − PWMalternate/SigRx+; (Control, Servo, Heater); (I2C,UART); 4 \\ 8 − PWMdirect/SigRx−; (Fan); 5 Vmin; 6 GND; SP3003−08ATG; SigM; SigP; PWMa; PWMd; Vsys; pGND−sGND; Vext−SigAlt; sGND; net=SigP:1; net=SigM:1; net=PWMd:1; net=PWMa:1; Vee; Vsys:1; Vext; Vext Vsys:1 2.2kR2

any downstream peripherials are to
sink Vext current to pGND.

If pGND−sGND is connected to
ground, netlists will show this
jumper shorted, effectively setting
minimum impedance grounding.

1

# PWR2

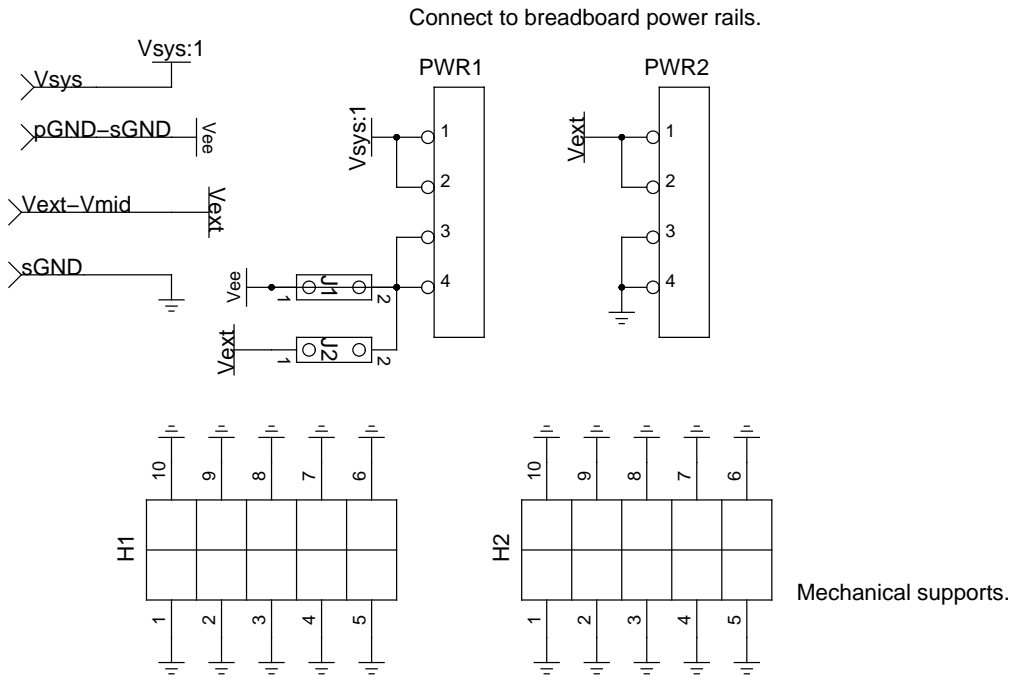
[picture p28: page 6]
Vext; Vee; Vsys; pGND−sGND; Vext−Vmid; sGND; Vsys:1; Vee Vext; Mechanical supports.

Connect to breadboard power rails.
PWR1

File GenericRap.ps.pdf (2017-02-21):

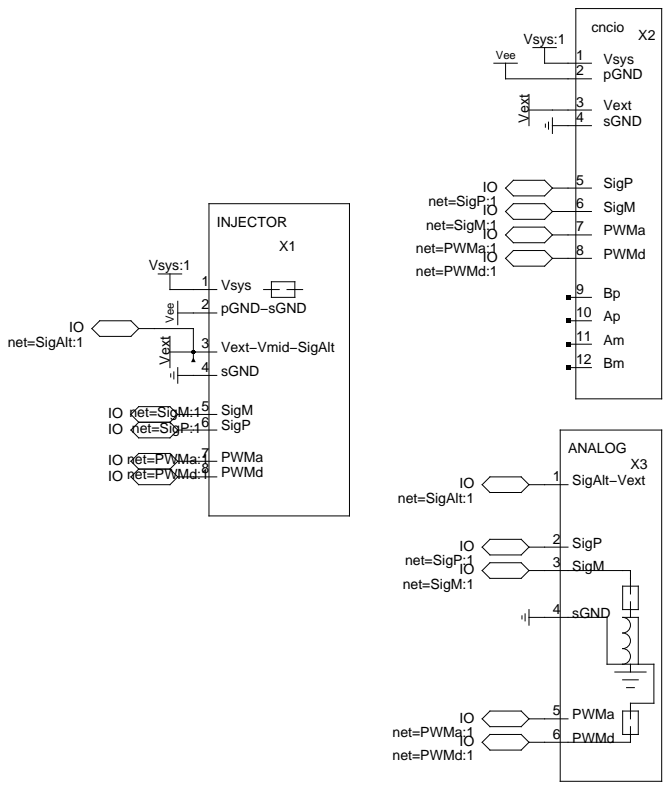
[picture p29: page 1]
1 Vsys 2 pGND; 3 Vext 4 sGND; 5 SigP 6 SigM; 8 PWMd; 7 PWMa; SigM 6; SigP

Vext net=SigAlt:1

IO net=SigM:1
IO net=SigP:1
IO net=PWMa:1
IO net=PWMd:1

net=SigM:1

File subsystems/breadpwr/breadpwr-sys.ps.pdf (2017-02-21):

Vee Vext; Mechanical supports.

Connect to breadboard power rails.
PWR1

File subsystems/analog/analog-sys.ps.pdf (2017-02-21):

SigAlt; net=SigAlt:1 IO

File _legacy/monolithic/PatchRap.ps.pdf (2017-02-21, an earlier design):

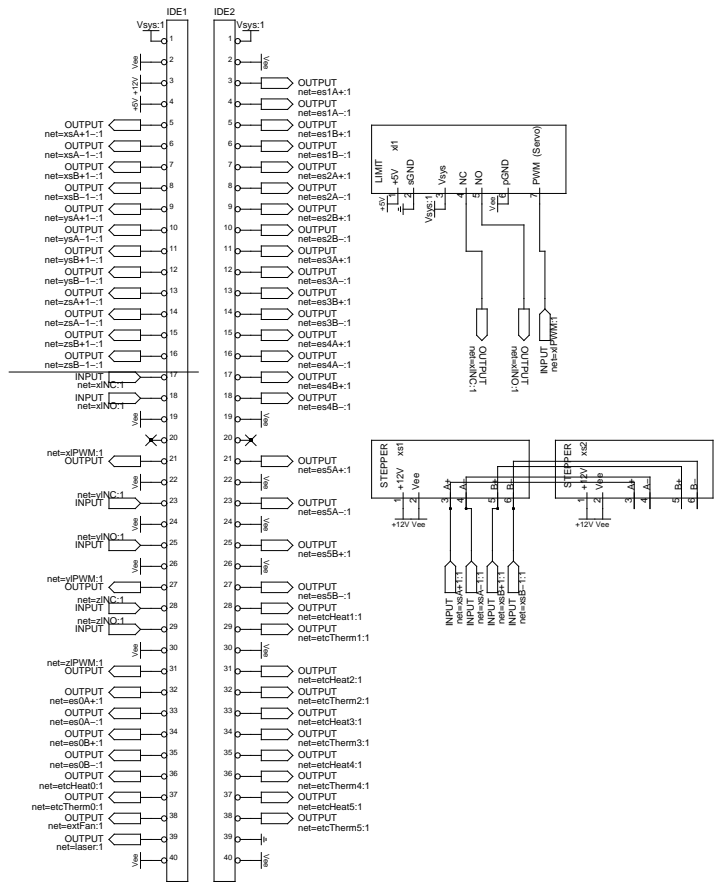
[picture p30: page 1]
+12V Vee; 7 (Servo)

Vee Vee Vee Vee Vee Vee Vee +5V +12V

Vee Vee Vee Vee Vee Vee Vee

net=ylNC:1 INPUT

net=ylNO:1 INPUT

net=ylPWM:1 OUTPUT

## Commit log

2015-08-26 Stepper subsystem drafted.
    [PatchRap.sch, stepper-sys.sch]
2015-08-27 Basic layout and pinout corrections.
    [PatchRap.sch]
2015-08-27 Multi-way power I/O planned.
    [PatchRap.sch]
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2015-08-27 XT60 footprints noted in schematic.
    [PatchRap.sch]
2015-08-27 Duplicate stepper connectors removed.
    [PatchRap.sch]
2015-08-29 Rough subsystem drafts.
    [accessory-sys.sch, extruder-sys.sch, laser-sys.sch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]
2015-08-29 Basic schematic.
    [PatchRap.sch]
2015-08-29 Some nets tagged for terminal barriers.
    [PatchRap.sch]
2015-08-29 Terminal block header in progress.
    [PatchRap.sch]
2015-08-30 Footprint for terminal strip.
2015-08-30 Stepper subsystem PCB layouts.
    [PatchRap.sch]
2015-08-30 Technically usable basic schematic.
    [PatchRap.sch]
2015-08-30 Minor tweaks, render image.
    [PatchRap.sch]
2015-08-30 Minor attribute bugfixes.
    [PatchRap.sch]
2015-08-30 Basic layout.
    [PatchRap.sch]
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2015-08-30 Duplicate stepper subsystems removed.
2015-08-30 Mostly valid stepper subsystem layouts.
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2015-08-30 Netname bugfix.
    [PatchRap.sch]
2015-08-31 Mostly usable layout.
    [PatchRap.sch]
2015-08-31 Preparation for routing.
    [PatchRap.sch]
2015-08-31 Prepared for autorouting and DRC checking in compliance with Oshpark and ITead fab requirements.
    [PatchRap.dsn]
2015-08-31 Attempted autorouting.
    [PatchRap.dsn]
2015-08-31 Mostly successful autorouting, import SES file failed (PCB software bug).
    [PatchRap.dsn]
2015-08-31 Successfully autorouted layout.
    [PatchRap.dsn, PatchRap.sch, stepper-sys.sch]
2015-08-31 Thicker 12mil traces autorouted.
    [PatchRap.dsn]
2015-08-31 Naming conventions improved for gEDA compliance.
    [PatchRap.sch, accessory-sys.sch, extruder-sys.sch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]
2015-08-31 Usable PCB.
    [PatchRap.dsn, extruder-sys.sch, laser-sys.sch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]
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2015-08-31 Production assets.
    [PatchRap.bottom.gbr, PatchRap.bottommask.gbr, PatchRap.bottompaste.gbr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]
2015-08-31 Shielded RJ45 jack breakout.
    [Jack.sch]
2015-09-01 Minor BOM bugfix.
    [PatchRap.sch, all.csv, mouser.csv]
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2015-11-14 Splitter in progress.
    [Splitter.dsn, Splitter.sch]
2015-11-14 Splitter design complete.
    [Splitter.dsn]
2015-11-16 Trivial PCB bugfix - double layer grounded through-holes.
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2016-10-09 New standard emphasizing modularity.
    [Jack.sch, PatchRap.sch, genericio-sys.sch]
2016-10-09 General purpose module in progress.
    [genericio-sys.sch]
2016-10-09 Basic schematic for generic module.
    [genericio-sys.sch]
2016-10-11 Footprint for cheaper, better shielded connector.
    [genericio-sys.sch]
2016-10-11 More comprehensive schematic.
    [genericio-sys.sch]
2016-10-11 Schematic cleanup.
    [genericio-sys.sch]
2016-10-12 More versaitle generic connector.
    [genericio-sys.sch]
2016-10-12 RepRap functionality divided away from subsystem.
    [GenericRap.sch, genericio-sys.sch]
2016-10-13 PCB layout in progress.
    [GenericRap.sch, cncio-sys.sch, genericio-sys.sch]
2016-10-16 Subsystem PCB layouts.
    [GenericRap.sch, cncio-sys.sch, genericio-sys.sch]
2016-10-18 Complete schematics for GenericRap module and related subsystems. Fault-tolerant LightPower and Hub interconnects.
    [GenericRap.sch, RN171-sys.sch, accessory-sys.sch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]
2016-10-18 Untracked files.
    [Hub.sch, LightPower.sch, RN171-sys.sch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]
2016-10-19 Layout preparations.
    [GenericRap.sch, LightPower.sch, cncio-sys.sch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]
2016-10-19 Injector routing in progress.
    [GenericRap.sch, injector-sys.sch]
2016-10-19 Basic injector component placement.
    [injector-sys.sch]
2016-10-19 Mostly usable injector layout.
    [injector-sys.sch]
2016-10-19 Provision for supplying Vmid to both sides of breadboard power rails.
    [breadpwr-sys.sch, injector-sys.sch]
2016-10-19 Analog subsystem layout.
    [GenericRap.sch, analog-sys.sch]
2016-10-20 Mechanically reinforced breadboard power connection.
    [breadpwr-sys.sch]
2016-10-20 Draft layout for GenericRap.
    [GenericRap.sch, analog-sys.sch]
2016-10-21 Optional LED indicator support, final traces in progress.
    [analog-sys.sch, cncio-sys.sch, genericio-sys.sch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]
2016-10-28 Splitter layout in progress, lack of Vsys diode surge suppression jumper noted for genericio subsystem.
    [Jack.sch, PatchRap.dsn, PatchRap.sch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]
2016-10-28 Autorouting path forced by internal terminal.
    [Splitter.sch, SplitterCore.dsn]
2016-10-28 Core routed.
    [Splitter.dsn, Splitter.sch, SplitterCore.dsn]
2016-10-28 Most splitter periphery routing.
    [Splitter.dsn, Splitter.sch, SplitterPeriphery.dsn]
2016-10-28 Guard layout.
    [guard-sys.sch]
2016-10-28 Greatly simplified splitter design.
    [Splitter.dsn, Splitter.sch, SplitterCore.dsn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]
2016-10-28 Fully featured GenericIO subsystem PCB layout.
    [Hub.sch]
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2017-02-02 Noted minor missing PCB trace.
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2017-02-21 Added stepper tester application, images prepared for more documentation.
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2017-03-08 Diagnostic pin labeling corrected.
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2020-06-19 Vext connected to SigAlt by default with trace marked. Vee to GND solderable jumper marked. Increased power trace thickness.
    [analog-sys.sch]
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2020-06-20 Manufacturing geometry.
    [GenericRap.bottom.gbr, GenericRap.bottommask.gbr, GenericRap.bottompaste.gbr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]
2020-06-25 Draft interconnect documentation.
    [Mini-Rambo.GBL, Mini-Rambo.GBO, Mini-Rambo.GBP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]
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2020-07-04 Complete build files for breakouts.
    [example.sch]
2020-07-04 Directory structure.
    [example.sch]
2020-07-09 Correct pin numbering - barrier terminal block .
2020-07-29 Common RJ45 jack symbols and footprints.
    [RJ45-Jack-1.sch, RJ45-Jack-2.sch, RJ45-T568A.sch]
2020-07-29 Remove prefixes.
    [analog-sys.sch, breadpwr-sys.sch, cncio-sys.sch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]
2020-08-25 Correct illustration stepper.
2020-08-25 Correct footprint attributes.
2020-08-29 Correct limit symbol pin assignment.
